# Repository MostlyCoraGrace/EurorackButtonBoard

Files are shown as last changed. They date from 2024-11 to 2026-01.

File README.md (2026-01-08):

# EurorackButtonBoard
 A modular, hot-swappable, and patchable, Eurorack-compatible simrig/buttonboard system.
 
 [Follow development on Hackaday](https://hackaday.io/project/199159-eurorack-buttonboard)

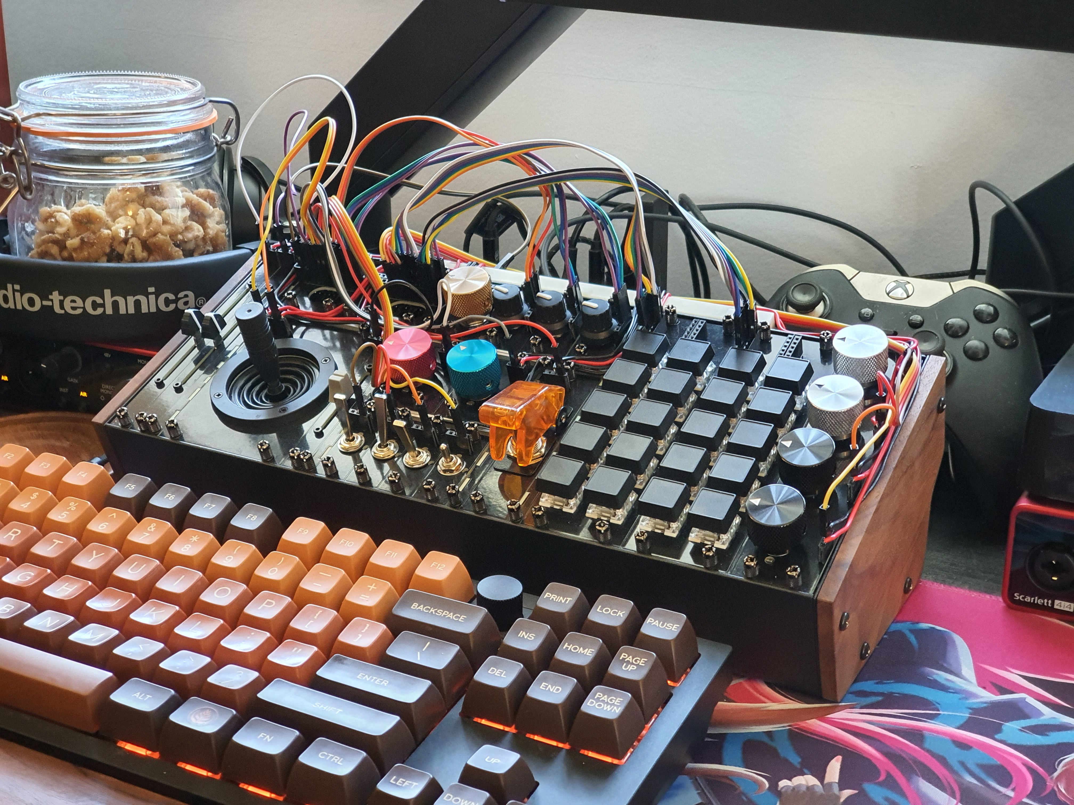
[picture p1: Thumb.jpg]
Crude CG render of several PCB modules arranged into a 60HP Eurorack case. There are many buttons, knobs, and sliders, arranged haphazardly.


# Special Thanks
- A special thanks has to go [PCBWay](https://pcbway.com/g/odjF56), for providing me with free PCBs (and discounts on PCBs when I ask for too many of them, because this project is *voluminous*).
- I would also like to thank my girlfriend, who gave me enough money to buy the first set of electronics I needed to make version 1 of this project. It was expensive.

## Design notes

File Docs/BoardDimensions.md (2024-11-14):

# Eurorack-compatible module specifications:

units in mm | 1U | 2U | 3U |
| ---: | --- | --- | --- |
| RU Height | 44.45 | 88.9 | 133.35
| Rail Clearance | 2.425 | 2.425 | 2.425
| Module Height | 39.65 | 84.05 | 128.5
| PCB Clearance | 8.575 | 8.912 | 9.25
| PCB Height | 22.5 | 66.226 | 110

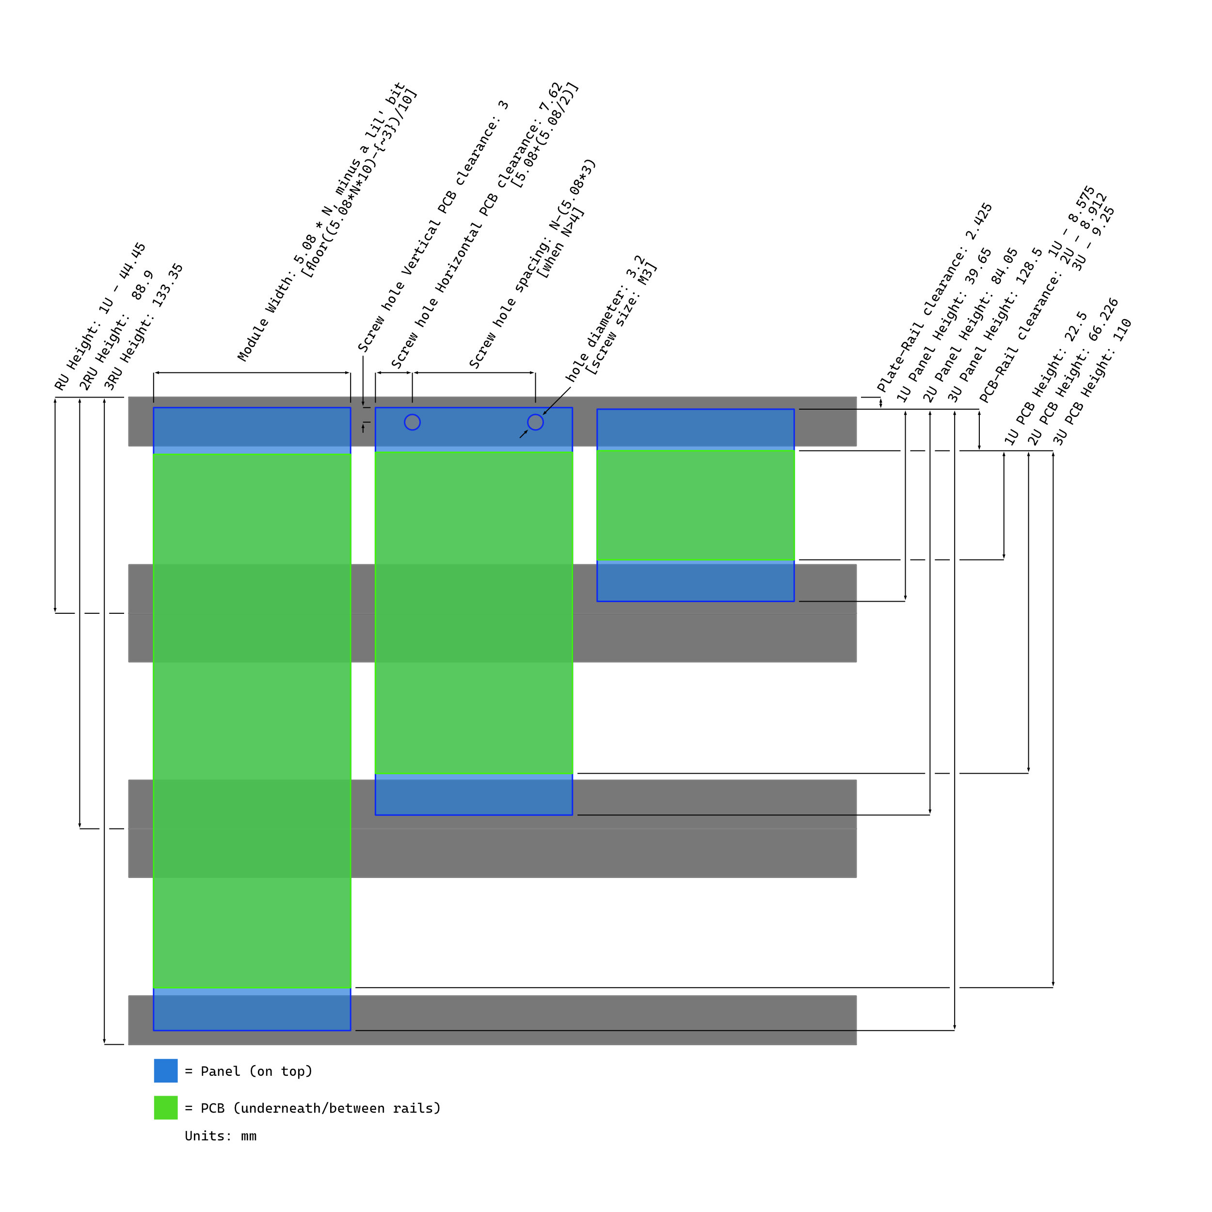
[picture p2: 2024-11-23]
Docs/Drawings/EurorackSizes.jpg

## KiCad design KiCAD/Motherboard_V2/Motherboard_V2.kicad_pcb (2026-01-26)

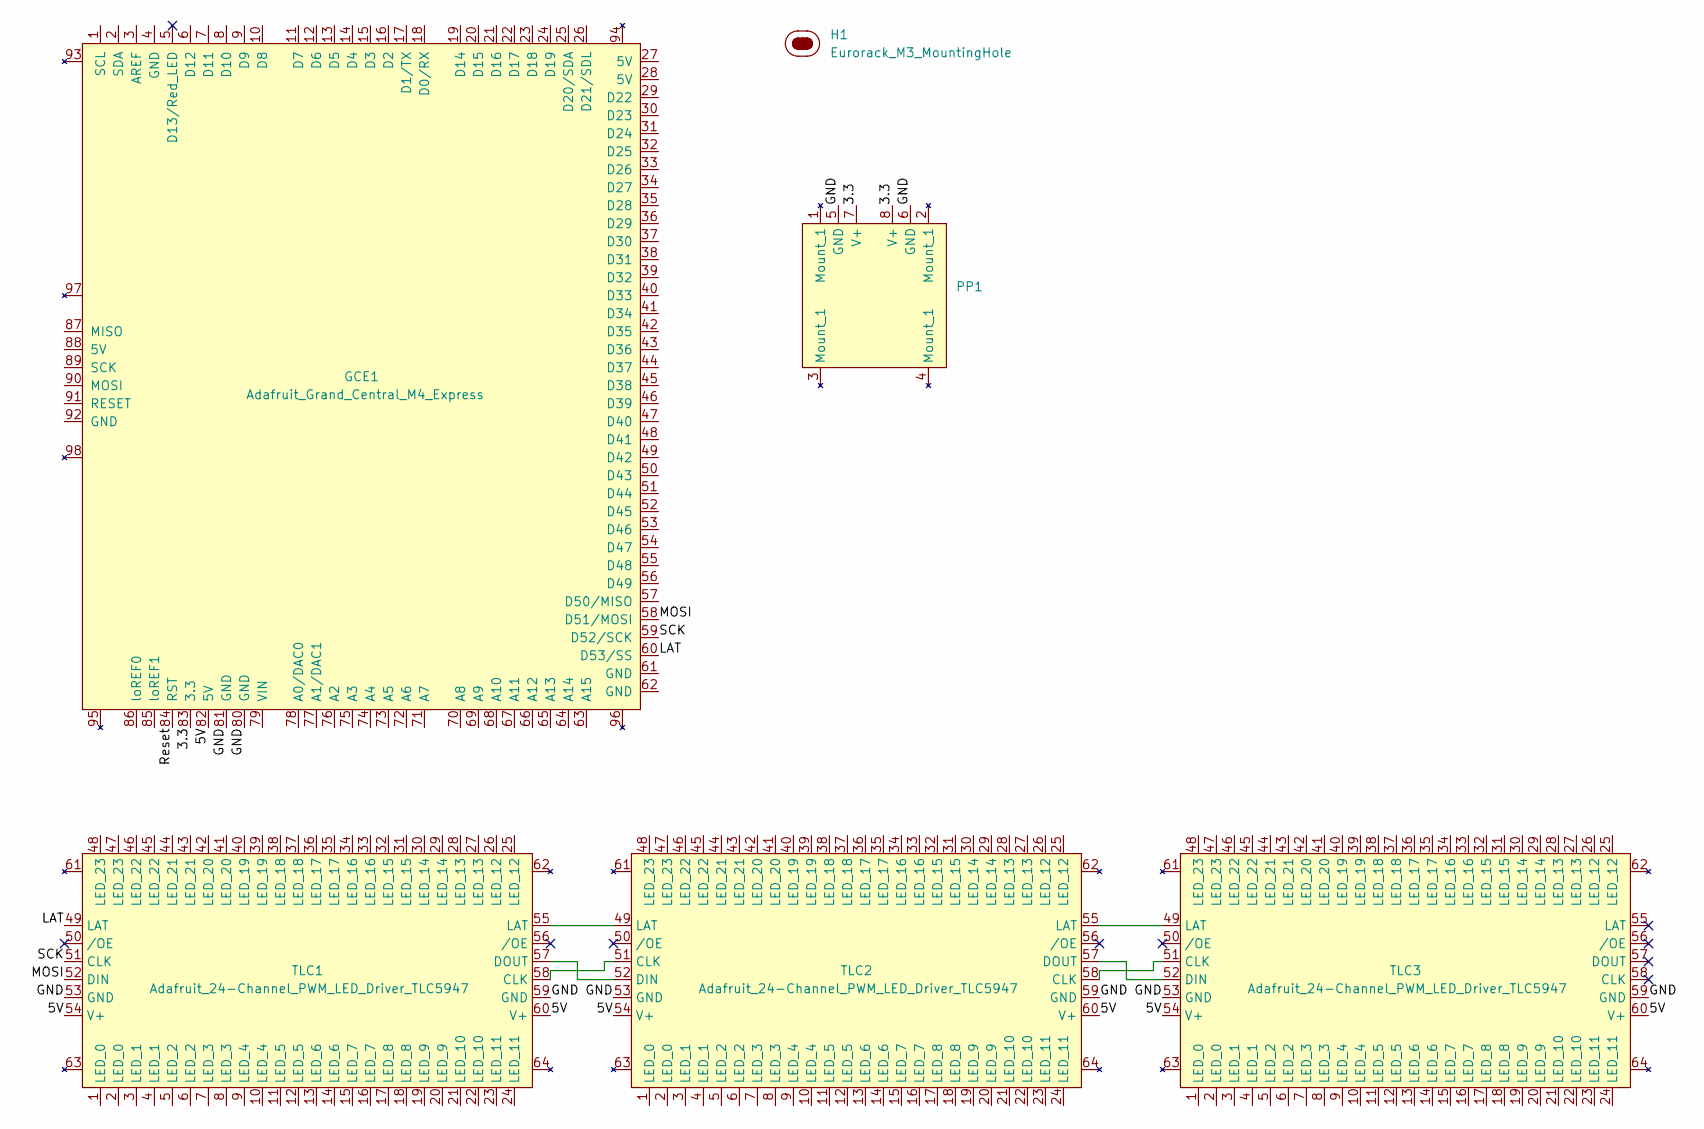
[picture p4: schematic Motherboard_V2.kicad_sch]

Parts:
GCE1: Adafruit_Grand_Central_M4_Express
H1: Eurorack_M3_MountingHole; MountingHole_3.2mm_M3
PP1: Adafruit_Perma-Proto_Mint-Tin-Size
TLC1, TLC2, TLC3: Adafruit_24-Channel_PWM_LED_Driver_TLC5947

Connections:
/3.3: GCE1.83 (3.3), PP1.7 (V+), PP1.8 (V+)
/5V: GCE1.82 (5V), TLC1.54 (V+), TLC1.60 (V+), TLC2.54 (V+), TLC2.60 (V+), TLC3.54 (V+), TLC3.60 (V+)
/GND: GCE1.80 (GND), GCE1.81 (GND), PP1.5 (GND), PP1.6 (GND), TLC1.53 (GND), TLC1.59 (GND), TLC2.53 (GND), TLC2.59 (GND), TLC3.53 (GND), TLC3.59 (GND)
/LAT: GCE1.60 (D53/SS), TLC1.49 (LAT)
/MOSI: GCE1.58 (D51/MOSI), TLC1.52 (DIN)
/Reset: GCE1.84 (RST)
/SCK: GCE1.59 (D52/SCK), TLC1.51 (CLK)
unnamed: TLC1.58 (CLK), TLC2.51 (CLK)
unnamed: TLC1.57 (DOUT), TLC2.52 (DIN)
unnamed: TLC1.55 (LAT), TLC2.49 (LAT)
unnamed: TLC2.58 (CLK), TLC3.51 (CLK)
unnamed: TLC2.57 (DOUT), TLC3.52 (DIN)
unnamed: TLC2.55 (LAT), TLC3.49 (LAT)

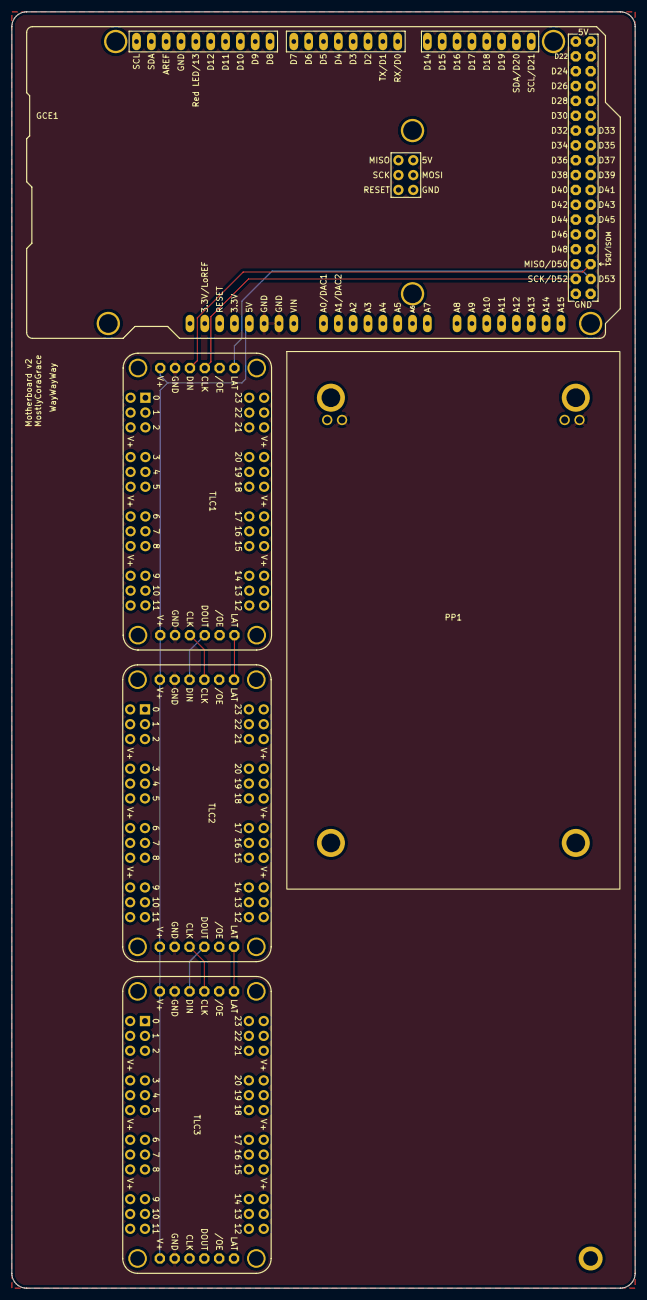
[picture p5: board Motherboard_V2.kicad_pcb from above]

Board: 2 copper layers, 106.7 x 218.4 mm, 6 parts (0 on the bottom side), 12 nets.

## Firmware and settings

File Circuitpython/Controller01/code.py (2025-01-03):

import board
import rotaryio
from joystick_xl.inputs import Axis, Button, Hat
from joystick_xl.joystick import Joystick

#Set up the joystick
joystick = Joystick()

joystick.add_input(
    Button(board.D0), # Large momentary switch
    Button(board.D1), # Large two-way momentary switch A
    Button(board.SDA), # Large two-way momentary switch B
    Button(board.SCL), # Large toggle switch
    Button(board.D2), # Small toggle switch
    Button(board.MISO), # Big missile switch
    Axis(board.A0), # Big joystick X axis
    Axis(board.A1), # Big joystick Y axis
    Axis(board.A2), # Little slider axis
    Axis(board.A3), # Large 1x knob Left
    Axis(board.A4), # Large 1x knob right
    Button(board.MOSI), # left Rotary encoder middle click
    Button(), # left Rotary encoder A
    Button(), # left Rotary encoder B
    Button(), # These buttons all come from the Neokey matrix
    Button(), # These buttons all come from the Neokey matrix
    Button(), # These buttons all come from the Neokey matrix
    Button(), # These buttons all come from the Neokey matrix
    Button(), # These buttons all come from the Neokey matrix
    Button(), # These buttons all come from the Neokey matrix
    Button(), # These buttons all come from the Neokey matrix
    Button(), # These buttons all come from the Neokey matrix
    Button(), # These buttons all come from the Neokey matrix
    Button(), # These buttons all come from the Neokey matrix
)

# Set up the rotary encoder inputs
ENC_A = board.A5
ENC_B = board.SCK

encoder = rotaryio.IncrementalEncoder(ENC_A, ENC_B)
encoder_pos = encoder.position
last_encoder_pos = encoder.position
encoder_value = 0

#Set up the NeoKey matrix
import keypad

COLUMNS = 2
ROWS = 5

keys = keypad.KeyMatrix(
    row_pins=(
        board.D5,
        board.D7,
        board.D9,
        board.D10,
        board.D11
    ),
    column_pins=(
        board.D12,
        board.D13,
    ),
    columns_to_anodes=False,
)

while True:
    # The encoder needs to be set manually
    encoder_pos = encoder.position # Get the current encoder position
    encoder_value = encoder_pos - last_encoder_pos # how does the encoder position differ
    if not encoder_value == 0:
        if encoder_value > 0:
            joystick.button[7].source_value = 1
            joystick.button[8].source_value = 0
        else:
            joystick.button[7].source_value = 0
            joystick.button[8].source_value = 1
    else:
        joystick.button[7].source_value = 1
        joystick.button[8].source_value = 1
    last_encoder_pos = encoder.position # Store the current encoder position for next time

    # The Neokey matrix sends events that we can react to.
    key_event = keys.events.get()
    if key_event:
        # Whenever there is an event for the key,
        # whether that be it being pressed or un-pressed,
        # we send the corresponding action to the joystick.
        joystick.button[key_event.key_number + 9].source_value = 0 if key_event.pressed else 1
    
    # Now we can continue
    joystick.update()

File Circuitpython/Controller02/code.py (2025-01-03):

import board  # type: ignore (this is a CircuitPython built-in)

from joystick_xl.inputs import Axis, Button, Hat
from joystick_xl.joystick import Joystick

joystick = Joystick()

joystick.add_input(
    Axis(board.A0), # Large Slider A
    Axis(board.A1), # Large Slider B
    Axis(board.A2), # Large 4x Knob A
    Axis(board.A3), # Large 4x Knob B
    Axis(board.A4), # Large 4x Knob C
#   Axis(board.A5), # Large 4x Knob D, but this one doesnt work :(
    Button(), # These buttons all come from the Neokey matrix
    Button(), # These buttons all come from the Neokey matrix
    Button(), # These buttons all come from the Neokey matrix
    Button(), # These buttons all come from the Neokey matrix
    Button(), # These buttons all come from the Neokey matrix
    Button(), # These buttons all come from the Neokey matrix
    Button(), # These buttons all come from the Neokey matrix
    Button(), # These buttons all come from the Neokey matrix
    Button(), # These buttons all come from the Neokey matrix
    Button(), # These buttons all come from the Neokey matrix
)

#Set up the NeoKey matrix
import keypad

COLUMNS = 2
ROWS = 5

keys = keypad.KeyMatrix(
    row_pins=(
        board.SCK,
        board.MOSI,
        board.MISO,
        board.D2,
        board.D13
    ),
    column_pins=(
        board.D12,
        board.D11,
    ),
    columns_to_anodes=False,
)

while True:

    # The Neokey matrix sends events that we can react to.
    key_event = keys.events.get()
    if key_event:
        
        # Whenever there is an event for the key,
        # whether that be it being pressed or un-pressed,
        # we send the corresponding action to the joystick.
        joystick.button[key_event.key_number].source_value = 0 if key_event.pressed else 1

    joystick.update()

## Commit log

2024-11-02 initialising repo
    started adding some of the parts etc
    [CherrySwitches_3U12HP5x3_V0-1.kicad_pcb, CherrySwitches_3U12HP5x3_V0-1.kicad_sch, CherrySwitches_3U15HP5x4_V0-1.kicad_pcb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]
2024-11-02 adding more modules
    more modules added
    [IlluminatedToggleSwitch_3U4HP1x.kicad_pcb, IlluminatedToggleSwitch_3U4HP1x.kicad_sch, RotaryEncoders_2U4HP3x.kicad_pcb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]
2024-11-03 adding more modules
    there are so many of them. im getting pretty good at this.
    [IlluminatedToggleSwitch_2U4HP1x.kicad_pcb, IlluminatedToggleSwitch_2U4HP1x.kicad_sch, RotaryEncoder_1U4HP1x.kicad_pcb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]
2024-11-03 more modules
    so many
    [RotarySelector_1U4HP1x.kicad_pcb, RotarySelector_1U4HP1x.kicad_sch, RotarySelectors_2U4HP2x.kicad_pcb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]
2024-11-03 added 1u toggle switch module
    added 1u toggle switch module
    [ToggleSwitch_1U3HP1x.kicad_pcb, ToggleSwitch_1U3HP1x.kicad_sch]
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2024-11-03 updated PCB widths to better conform to Eurorack standards
    [CherrySwitches_3U12HP5x3_V0-1.kicad_pcb, CherrySwitches_3U15HP5x4_V0-1.kicad_pcb, CherrySwitches_3U4HP5x_V0-1.kicad_pcb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]
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2024-11-03 added 3u 3x rotary potentiometer module
    [RotaryPotentiometer_3U6HP3x.kicad_pcb, RotaryPotentiometer_3U6HP3x.kicad_sch]
2024-11-03 added 3u 4x rotary potentiometer module
    [RotaryPotentiometer_3U6HP4x.kicad_pcb, RotaryPotentiometer_3U6HP4x.kicad_sch]
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2024-11-04 added linear potentiometer 3u2hp1x module
    [LinearPotentiometer_3U2HP1x.kicad_pcb, LinearPotentiometer_3U2HP1x.kicad_sch]
2024-11-04 added Cherry Switches 2u4hp3x module
    [CherrySwitches_2U4HP3x.kicad_pcb, CherrySwitches_2U4HP3x.kicad_sch]
2024-11-04 added cherry switches 2u8hp3x2 module
    [CherrySwitches_2U8HP63x2.kicad_pcb, CherrySwitches_2U8HP63x2.kicad_sch]
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2024-11-05 fixed silkscreen on cherryswitches_1u12hp1x3 module
    [CherrySwitches_1U12HP1x3.kicad_pcb]
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2024-11-05 fixed blank 2u1hp screw mount silkscreens
    [Blank_2U1HP.kicad_pcb]
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2024-11-05 added JLCPCB gerber generation settings for blank 1u1hp module
    [Blank_1U1HP.kicad_pcb]
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2024-11-06 added a 2-part 3u to 3x 1u adapter pcb
    [3U-1U_Adapter_3U1HP3x_A.kicad_pcb, 3U-1U_Adapter_3U1HP3x_A.kicad_sch, 3U-1U_Adapter_3U1HP3x_B.kicad_pcb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]
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2024-11-06 added alternate smaller 5hp variant of rotary potentiometer 3u5hp3x module
    [RotaryPotentiometer_3U5HP3x.kicad_pcb, RotaryPotentiometer_3U5HP3x.kicad_sch]
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2024-11-07 updated cherry 5x4 module with copper fills and no front silkscreen text for a cleaner look and maybe better structural rigidity
    [CherrySwitches_3U15HP5x4.kicad_pcb]
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2024-11-07 removed all front silkscreen, and flipped most modules, to make the boards 'cleaner'.
    [2U-1U_Adapter_2U1HP2x_A.kicad_pcb, 2U-1U_Adapter_2U1HP2x_B.kicad_pcb, 3U-1U_Adapter_3U1HP3x_A.kicad_pcb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]
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2024-11-08 added copper fills to every module, to maybe possibly increase structural rigidity.
    [2U-1U_Adapter_2U1HP2x_A.kicad_pcb, 2U-1U_Adapter_2U1HP2x_B.kicad_pcb, 3U-1U_Adapter_3U1HP3x_A.kicad_pcb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]
2024-11-10 added PCBWay print identification silkscreen text to each component
    [2U-1U_Adapter_2U1HP2x_B.kicad_pcb, 3U-1U_Adapter_3U1HP3x_B.kicad_pcb, Blank_1U1HP.kicad_pcb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]
2024-11-23 fixed diagram showing the wrong measurement for pcb-rail clearance
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2025-03-02 added a two-part 1U switch module with an LED
    [ToggleSwitch_1U7HP1x_A.kicad_pcb, ToggleSwitch_1U7HP1x_A.kicad_sch, ToggleSwitch_1U7HP1x_B.kicad_pcb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]
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2025-03-10 fixed mounting hole positioning for ToggleSwitch_1U7HP1x_A
    [ToggleSwitch_1U7HP1x_A.kicad_pcb]
2025-03-10 updated the panel-mounted LED footprint to account for a slightly larger hex nut
    [ToggleSwitch_1U7HP1x_A.kicad_pcb, ToggleSwitch_1U7HP1x_B.kicad_pcb]
2025-12-21 starting to populate the V2 panels in KiCAD. Cleared out the old V1 panels.
    [2U-1U_Adapter_2U1HP2x_A.kicad_pcb, 2U-1U_Adapter_2U1HP2x_A.kicad_sch, 2U-1U_Adapter_2U1HP2x_B.kicad_pcb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]
2025-12-22 added 1U to 3U adapter board kicad files
    [Adapter_1U27HP3uAv2.kicad_pcb, Adapter_1U27HP3uBv2.kicad_pcb, Adapter_1U27HP3uBv2.kicad_sch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]
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2025-12-23 fixed new 6.35mm toggle switch footprint. the lil nubbin it had for the cutout would have caused issues with the switch in other orientations. i thought i was being clever, but i was just shooting my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
    [ToggleSwitch_1U6HP1x1Av2.kicad_pcb, ToggleSwitch_wH_1U7HP1x1Av2.kicad_pcb, ToggleSwitch_wH_1U9HP1x1Av2.kicad_pcb]
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2025-12-23 added more lengths of module to the module lengths table
    [ModuleWidths.ods]
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2025-12-24 updated the 25mm handle for 1u modules. its footprints and symbols now correctly link to where i get them, and have descriptions for what each of its A and B parts do
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2025-12-24 added a large knob and a rotary encoder module
    [LargeKnob_wH_1U11HP1x1Av2.kicad_pcb, LargeKnob_wH_1U11HP1x1Av2.kicad_sch, LargeKnob_wH_1U11HP1x1Bv2.kicad_pcb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]
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2025-12-25 updated the rotary selector footprint to have the notch it requires to be mounted correctly.
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2025-12-25 added a 45mm slide pot with handle module
    [SlidePot_45mm_wH_1U14HP1x1Av2.kicad_pcb, SlidePot_45mm_wH_1U14HP1x1Av2.kicad_sch, SlidePot_45mm_wH_1U14HP1x1Bv2.kicad_pcb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]
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2025-12-27 fixed the silkscreen on the joystick top footprint
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2025-12-28 added a 1hp and a 2hp 2u-to-1u adapter modules
    [Adapter_2U1HPAv2.kicad_pcb, Adapter_2U1HPAv2.kicad_sch, Adapter_2U1HPBv2.kicad_pcb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]
2025-12-28 fixed silkscreens on adapter_2u2hpbv2
    [Adapter_2U2HPBv2.kicad_pcb]
2025-12-28 added a variant of the adapter_2u2hpbv2 which has a handle
    [Adapter_wH_2U2HPAv2.kicad_pcb, Adapter_wH_2U2HPAv2.kicad_sch, Adapter_wH_2U2HPBv2.kicad_pcb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]
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2025-12-28 added slide pot 45mm 2u6hp1x1 with handle module
    [SlidePot_45mm_wH_2U6HP1x1Av2.kicad_pcb, SlidePot_45mm_wH_2U6HP1x1Av2.kicad_sch, SlidePot_45mm_wH_2U6HP1x1Bv2.kicad_pcb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]
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2025-12-28 added another illuminated toggle switch module, this time with a handle
    [IlluminatedToggleSwitch_wH_2U8HP1x1Av2.kicad_pcb, IlluminatedToggleSwitch_wH_2U8HP1x1Av2.kicad_sch, IlluminatedToggleSwitch_wH_2U8HP1x1Bv2.kicad_pcb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]
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2025-12-30 added mechanical solder pads to the adapter boards that were missing them. woops!
    [Adapter_2U1HPAv2.kicad_pcb, Adapter_2U1HPAv2.kicad_sch, Adapter_2U2HPAv2.kicad_pcb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]
2025-12-30 fixed up silkscreens on some boards
    [Adapter_2U1HPAv2.kicad_pcb, Adapter_2U2HPAv2.kicad_pcb, Adapter_2U2HPCv2.kicad_pcb]
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2025-12-31 updated the 1u->3u adapter board to work better
    [Adapter_1U27HP3uAv2.kicad_pcb, Adapter_1U27HP3uAv2.kicad_sch, Adapter_1U27HP3uBv2.kicad_pcb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]
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2026-01-05 updated all modules to use plated through-holes wherever possible
    [Adapter_1U27HP3uAv2.kicad_pcb, Adapter_1U27HP3uBv2.kicad_pcb, Adapter_2U1HPAv2.kicad_pcb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]
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2026-01-25 expanded tolerances for the illuminated toggle switch, since it also sucks
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2026-01-27 adjusted positioning of the slide pots in 3u5hp2x1 to fix tolerance issues
    [SlidePot_75mm_3U5HP2x1Av2.kicad_pcb, SlidePot_75mm_3U5HP2x1Bv2.kicad_pcb]
